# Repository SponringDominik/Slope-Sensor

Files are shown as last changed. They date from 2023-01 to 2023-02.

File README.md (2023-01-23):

# Building a slope-sensor for ski mountaineering

The danger of avalanches is directly related to the slope. Measuring slopes
during ski touring helps getting a better feeling for the terrain, and thus,
avoiding dangerous routes. In addition, it can be a helpful argumentation aid to find out whether a face really has its >50° as stated in the guidebook or a rather more realistic 42°.

Since we were too stingy to spend 85 EUR on the [slope sensor by Pieps](https://www.pieps.com/produkt/30-plus-xt), 
we rather spent 300 EUR on material and several weekends of our time to make our
own one. In this document, we lay out what we learned and provide instructions
how to build your own. 

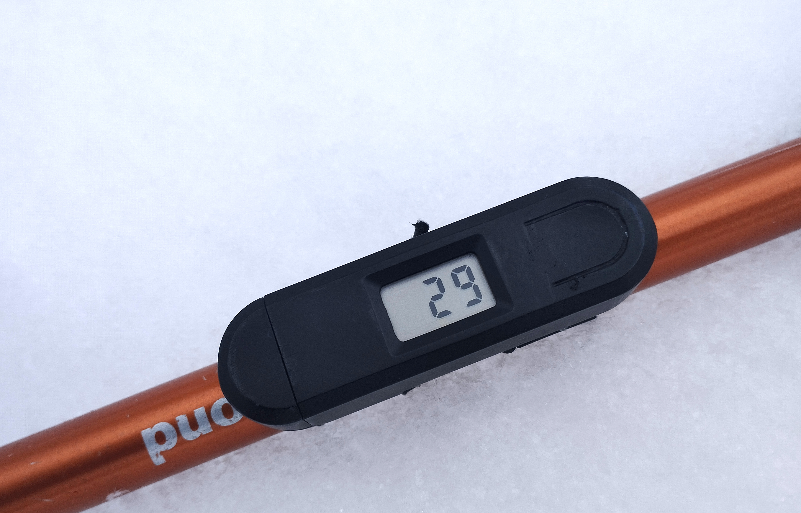
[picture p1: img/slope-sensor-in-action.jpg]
slope-sensor


## Specification of the final product:
Our product showed the following specifications, which we measured: 
  
Weight: < 20g  
Dimension(LxWxT): 75x21.5x12  
Standby current: <300nA  
Active current: <400µA  
  
The estimated battery life is >10 years in standby or >20k measurements, whichever comes first.

## Operating principle
The product is designed to be mounted on a ski pole to ensure a more robust measurement of the slope. For this purpose, it has two rubber cords with which it can be attached to the ski pole. Pressing the button on the right side awakes the device from sleep-mode and displays the slope angle. Each subsequent press toggles between the slope-measurement-mode and the temperature-measurement-mode. 20 seconds after the last press of the button, the device automatically switches to sleep-mode.

```mermaid
stateDiagram-v2
    [*] --> sleep: insert battery
    sleep --> slope: button
    slope --> temperature: button
    temperature --> slope: button
    temperature --> sleep: 20s
    slope --> sleep: 20s
```

## Choosing components
The first component to be selected was the display, because it governs the size of the device and its power consumption. We decided on a 7-segment LCD with 4 digits. The outer right digit is completely covered by the housing and electrically inaccessible. Of the outer left digit, only segment G is used to create a negative sign. To control the LCD, an LCD-driver is required that can address at least 15 segments. 

We chose a 3-axis accelerometer to measure the tilt angle. The accelerometer is aligned so that its X-axis is parallel to the pole axis. To obtain the tilt angle, the angle between the acceleration vector - which at rest corresponds to the gravity vector - and the X-component of the acceleration vector must be calculated.

<p align="center">
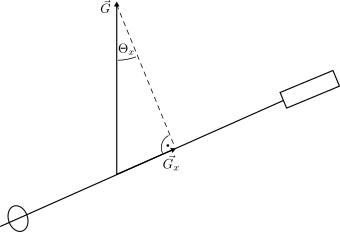
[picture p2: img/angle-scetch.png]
  
</p>

$$\Theta_x = \arcsin{\Bigg(\frac{|\vec{G}_x|}{|\vec{G}|}\Bigg)}$$

An ATtiny424 microcontroller orchestrates communication with the components and performs the calculations. 

For the power supply a 3V lithium button cell is used. The size of the battery is chosen such that it just fits into the housing of the device. A CR-1225 is most suitable and can usually supply at least 40mAh.

The following table lists all the components used on the PCB.
No | Component | Specification | Quantity | Manufacturer Product Number
-|-|-|-|-
U1 | Microcontroller | [ATtiny424](https://www.digikey.at/en/products/detail/microchip-technology/ATTINY424-SSU/13415020) | 1 | ATTINY424-SSU
U2 | Accelerometer | [MC3632](https://www.digikey.at/en/products/detail/memsic-inc/MC3632/15292805) | 1 | MC3632
U3 | Display Driver | [BU91796](https://www.digikey.at/en/products/detail/rohm-semiconductor/BU91796FS-ME2/12359485) | 1 | BU91796FS-ME2
U4 | LCD | [DE117](https://www.tme.eu/at/details/de117-rs-20_7.5/digitale-lcd-displays/display-elektronik/de-117-rs-20-7-5-v) | 1 | DE 117-RS-20/7,5
TH1 | PTC-Resistor | [TMP64](https://www.digikey.at/en/products/detail/texas-instruments/TMP6431DECR/11635694) | 1 | TMP6431DECR
SW1 | Switch | [PTS636](https://www.digikey.at/en/products/detail/c-k/PTS636-SK25F-SMTR-LFS/10071743) | 1 | PTS636 SK25F SMTR LFS
BT1 | Battery Holder | [BH-127A-1](https://www.digikey.at/en/products/detail/adam-tech/BH-127A-1/13537744) | 1 | BH-127A-1
C1 | Capacitor | [100n](https://www.digikey.at/en/products/detail/kemet/C0805C104M3RAC7800/2211748) | 1 | C0805C104M3RAC7800
R1,R2 | Resistor | [4k7](https://www.digikey.at/en/products/detail/stackpole-electronics-inc/RMCF0805FT4K70/1760659) | 2 | RMCF0805FT4K70
R3 | Resistor | [47k](https://www.digikey.at/en/products/detail/stackpole-electronics-inc/RMCF0805FT47K0/1760299) | 1 | RMCF0805FT47K0

The following table lists all the other components used to build this slope sensor. A link to an example is also listed for each component.
Part | Specification
-|-
Connector | [ZEC 1,0/ 3-ST-3,5 C1 R1,3](https://www.digikey.at/en/products/detail/phoenix-contact/1893698/2553237)
Battery | [CR1225](https://www.conrad.at/de/p/gp-batteries-gppbl1225000-knopfzelle-cr-1225-lithium-62-mah-3-v-1-st-2446350.html)
O-Ring | [10.5 x 1.5](https://www.o-ring-stocks.eu/o-ring-10.5x1.5-nbr-nitrile-70-shore-a-black-ors113871)
Screw | [ISO 7050 - ST2,2 x 6,5 - A4-20H - C - H](https://online-schrauben.de/shop/Schrauben/Blechschrauben/DIN-7982-Form-CH-Senkkopf-Blechschrauben-mit-Phillips-Kreuzschlitz-und-Spitze-aehnl.-ISO-7050/Edelstahl-Ros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,2-mm-Schraubendurchmesser)
Rubber cord | [2mm](https://www.amazon.de/perdix-Gummischnur-Gummikordel-Gummiband-Rucksack/dp/B0BB4V88YH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)

## Prototyping

## Programming the microcontroller

## CAD

## 3D-printing the case

## Final tests

## Conclusions

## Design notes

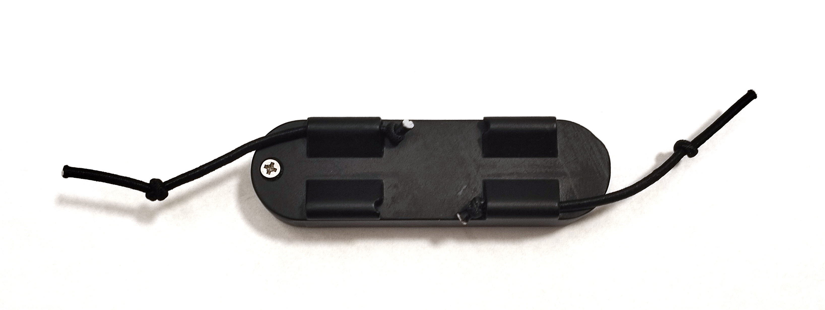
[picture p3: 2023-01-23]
img/slope-sensor-bottom.jpg

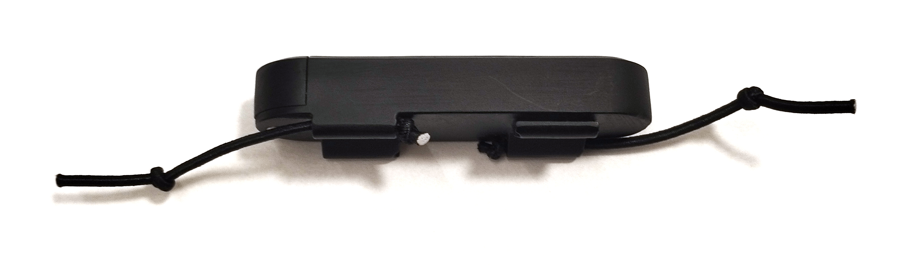
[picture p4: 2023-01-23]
img/slope-sensor-side.jpg

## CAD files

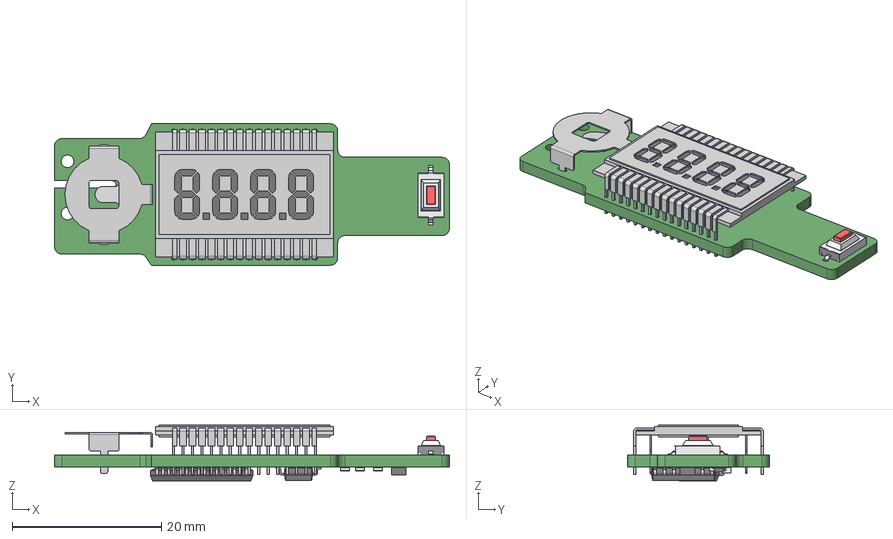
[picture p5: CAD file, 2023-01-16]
CAD/PCB.step
53.0 x 19.0 x 7.47 mm

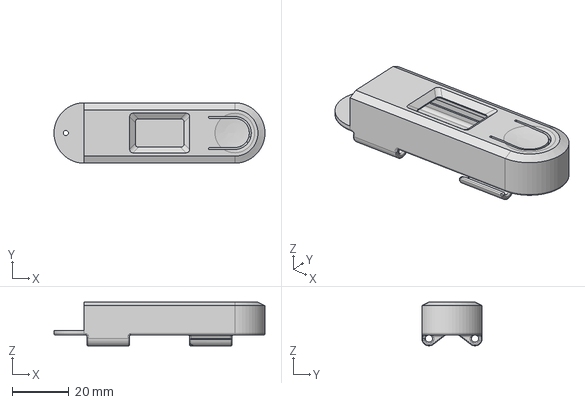
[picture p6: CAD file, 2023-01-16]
CAD/Case.step
74.7 x 21.4 x 15.5 mm

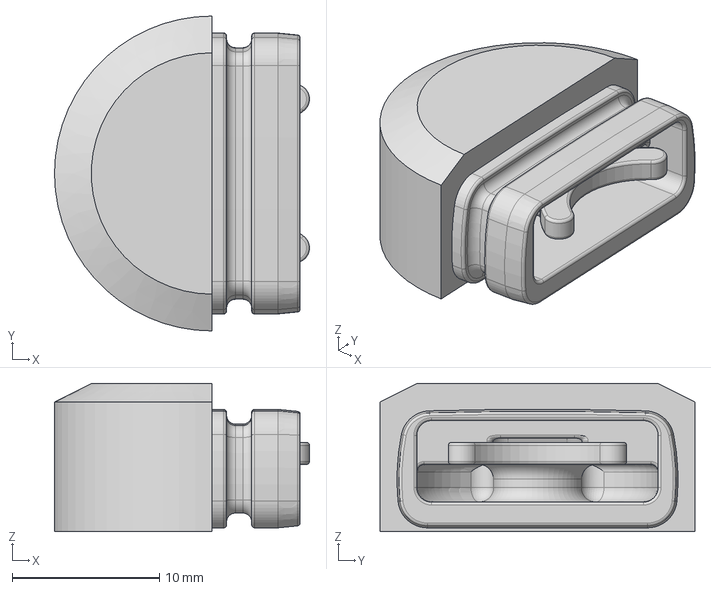
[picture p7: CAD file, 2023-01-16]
CAD/Cap.step
17.3 x 21.4 x 10.1 mm

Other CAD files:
CAD/Slope-Sensor_asm.f3z

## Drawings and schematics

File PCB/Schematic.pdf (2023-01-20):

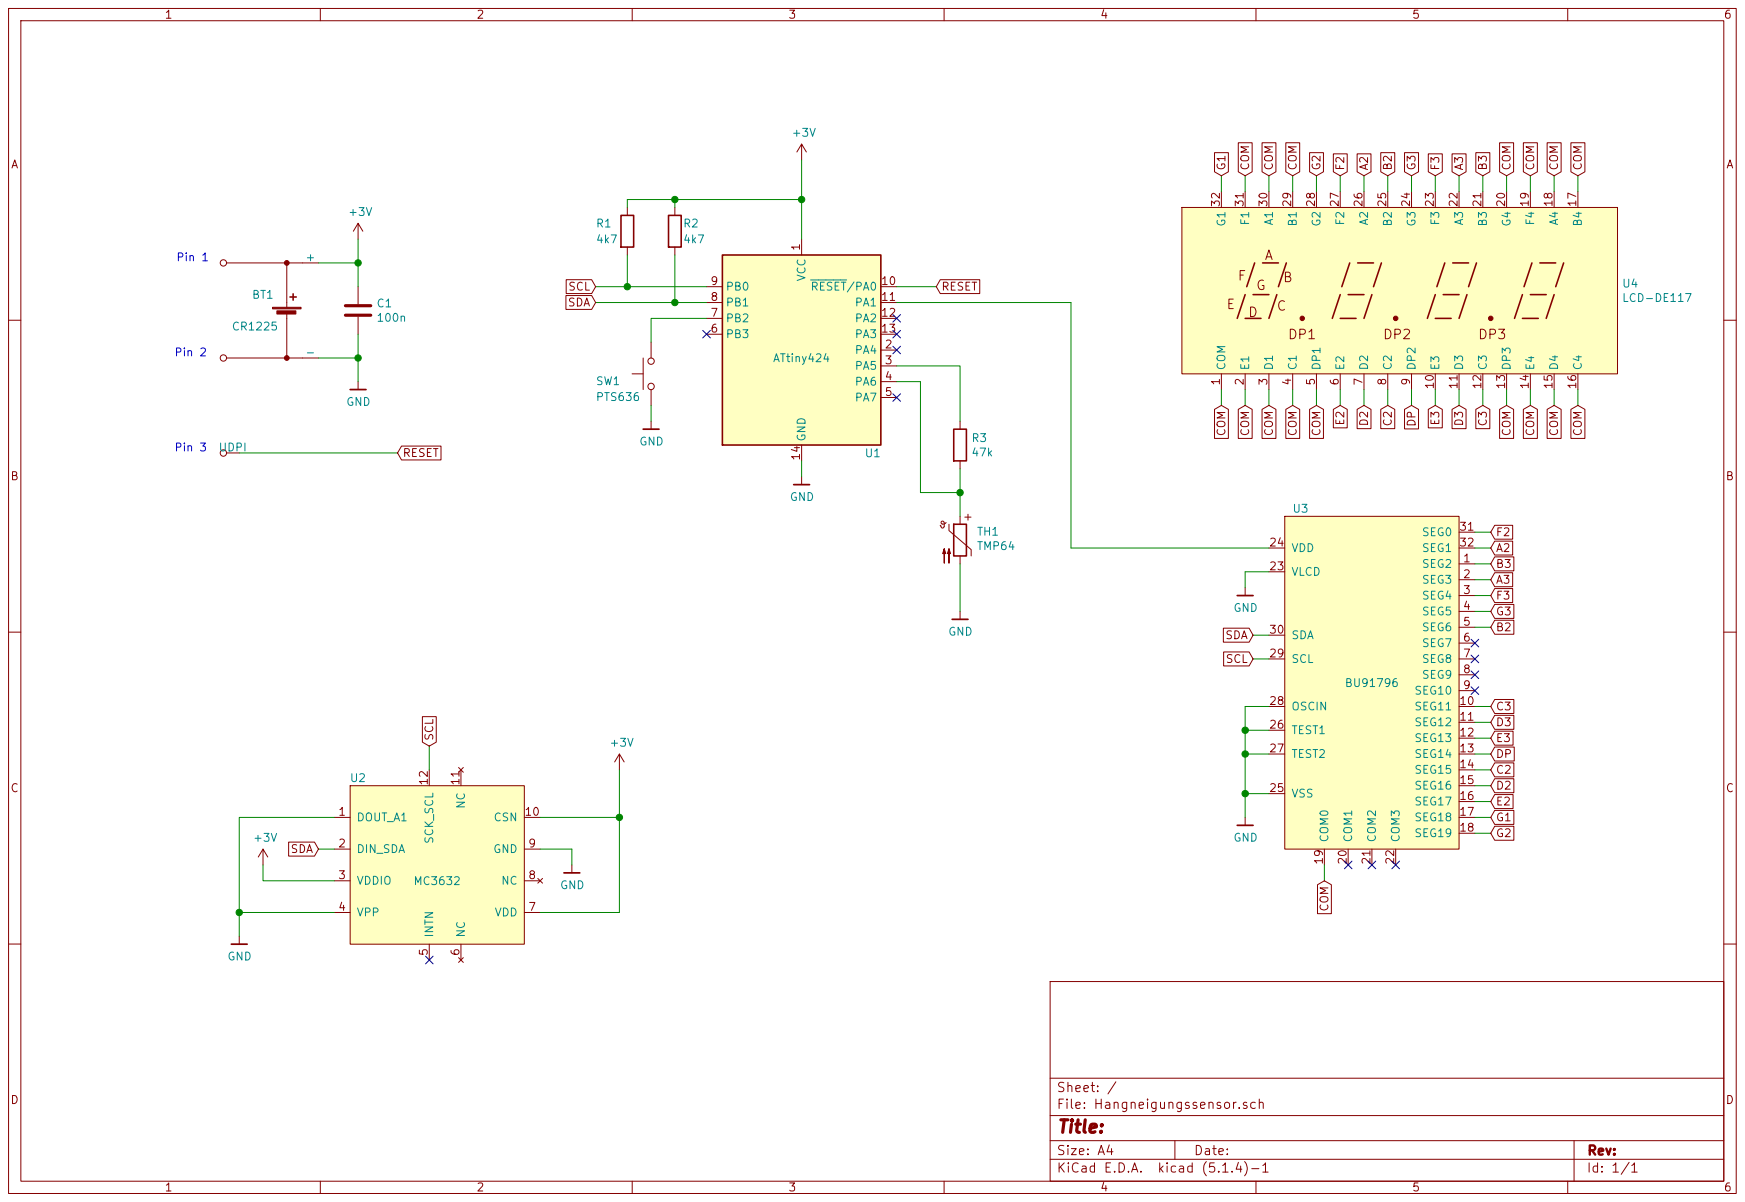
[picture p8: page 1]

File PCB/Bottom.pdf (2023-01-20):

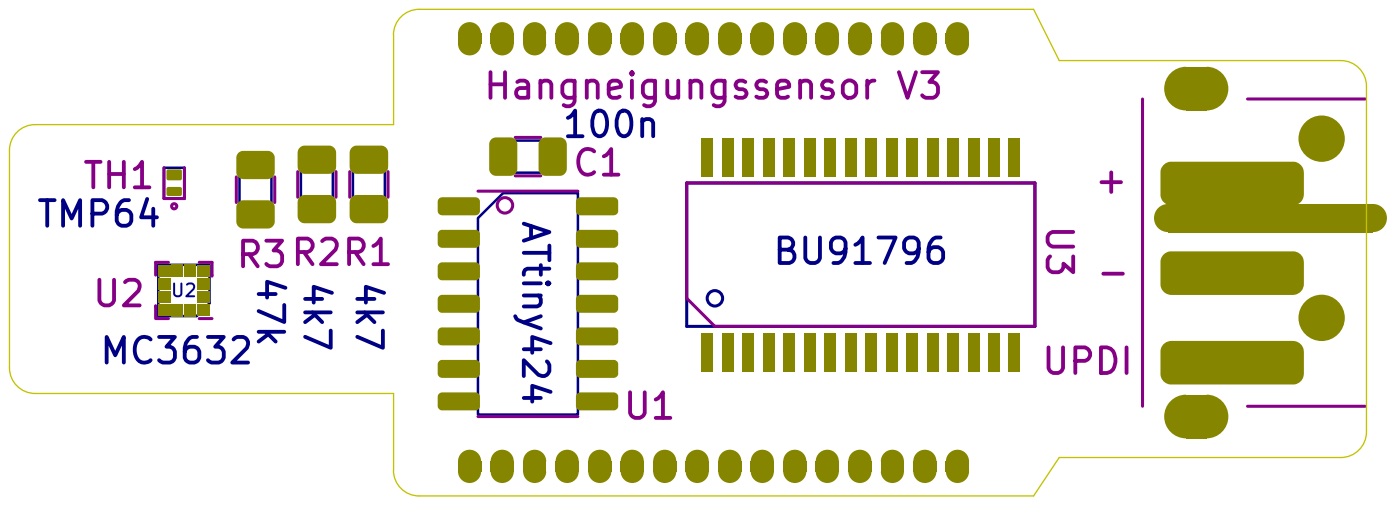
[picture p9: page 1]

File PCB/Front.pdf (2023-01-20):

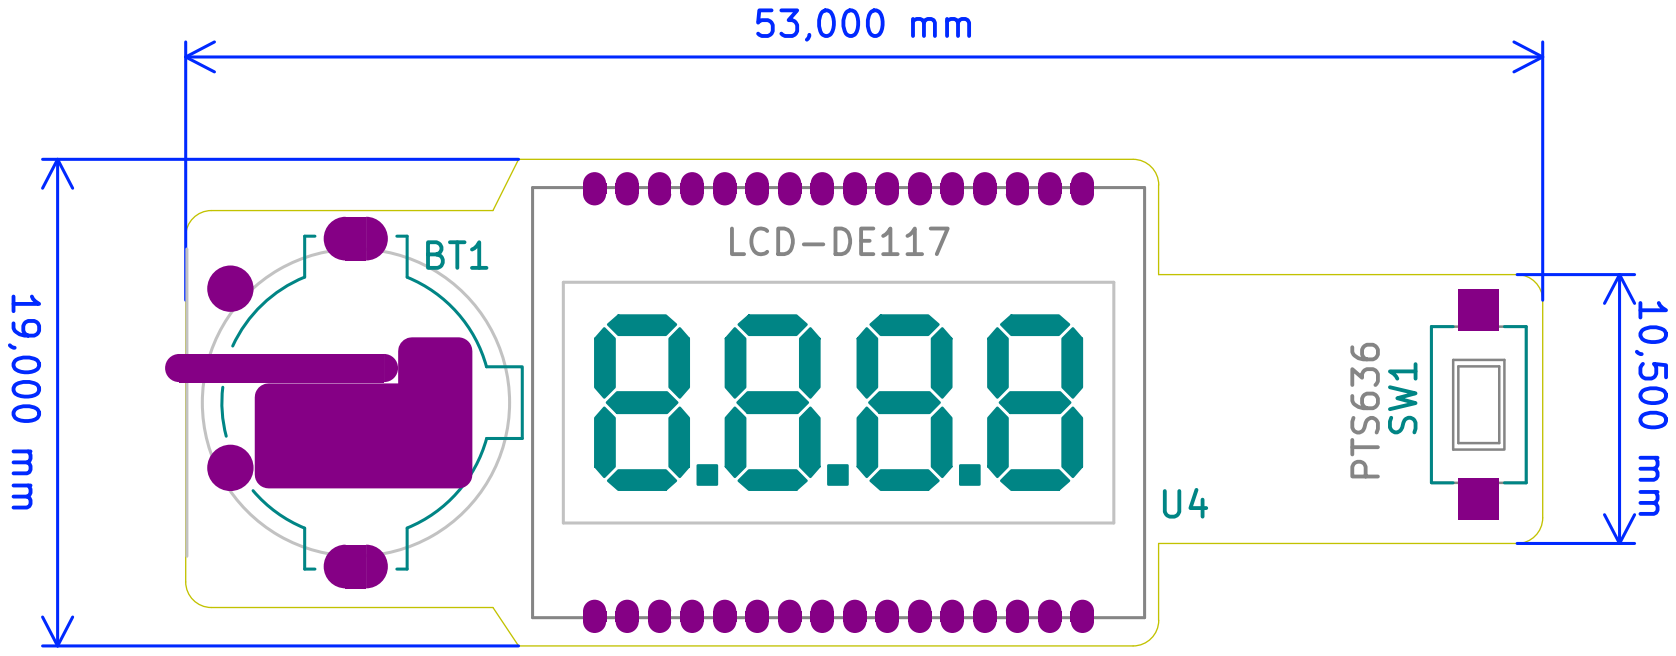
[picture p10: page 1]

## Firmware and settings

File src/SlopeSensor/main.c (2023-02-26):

/************************************************************************/
/* SlopeSensor															*/
/************************************************************************/
#include <avr/io.h>
#include <avr/interrupt.h>
#include <stdlib.h>
#include <math.h>
#include <stdbool.h>
#include "mcu_init.h"
#include "i2c_master.h"
#include "accel_util.h"
#include "lcd_util.h"

/*------------------------------------------------------------------------------------*/
// Zeit, die der Microcontrollers nach Tasterbetätigung wach bleibt in 10ms
#define WAKE_TIME 2000
// Entprell-Zeit des Tasters in 10ms
#define DEBOUNCE 10
// Vorwiderstand des Thermistors R3:
//	0: NTC-Variante
//	1: PTC-Variante
#if (0)
#  define R3_PTC 46250
#else
#  define R3_NTC 10700
#endif



/* Globale Variablen -----------------------------------------------------------------*/
// Laufzeit in 10ms
uint16_t millisecond_10;
// Laufzeit, bis der Microcontroller schlafen geht in 10ms
uint16_t sleep_at_millis = WAKE_TIME;
// Bis zu dieser Zeit wird eine Zustandsänderung des Tasters ignoriert (Prellen)
uint16_t wait_time = 0;
// Zustand des Sensors:
//		0: Winkel messen
//		1: Temperatur messen
uint8_t State = 0;


/*------------------------------------------------------------------------------------*/
/* Power-Save aktivieren */
void go_sleep(void){
	// Timer Stoppen
	TCA0.SINGLE.CTRLA &= ~TCA_SINGLE_ENABLE_bm;	
	// Accelerometer ausschalten
	accel_gosleep();
	// Display ausschalten
	PORTA.OUTCLR = LCD_EN;	// Schalte Versorgung für LCD aus
	// Zustände wieder zurücksetzen
	millisecond_10 = 0;
	State = 0;
	sleep_at_millis = WAKE_TIME;
	wait_time = 0;
	// Interrupt für Flankenänderung aktivieren
	PORTB.PIN2CTRL &= ~PORT_ISC_gm;
	PORTB.PIN2CTRL |=PORT_ISC_BOTHEDGES_gc;	
	// Schlafen gehen
	// Sleep-Mode auf Power-Down stellen und Sleep-Enable aktivieren
	SLPCTRL.CTRLA = SLPCTRL_SEN_bm | SLPCTRL_SMODE_PDOWN_gc;
	// Assembler Befehl "Sleep" startet ausgewälten Sleep-Modus
	// Sleep-Enable muss davor gesetzt werden (möglichst direkt davor)
	asm("SLEEP");
	
	
	// Wake-Up Sequenz
	// Accelerometer aktivieren
	accel_wakeup();
	// Versorgung für LCD einschalten
	PORTA.OUTSET = LCD_EN;
	lcd_init();
	// Timer zurücksetzen und starten
	TCA0.SINGLE.CNTL = 0;
	TCA0.SINGLE.CNTH = 0;
	TCA0.SINGLE.CTRLA |= TCA_SINGLE_ENABLE_bm;
}

/* Ruhemodus aktivieren */
void go_idle(void){
	// Sleep-Mode auf IDLE stellen und Sleep-Enable aktivieren
	SLPCTRL.CTRLA = SLPCTRL_SEN_bm | SLPCTRL_SMODE_IDLE_gc;
	// Assembler Befehl "Sleep" startet ausgewälten Sleep-Modus
	// Sleep-Enable muss davor gesetzt werden (möglichst direkt davor)
	asm("SLEEP");
}


#ifdef R3_NTC
/* Lese ADC aus und berechne Temperatur */
int8_t get_temperature(void){
	// Tabelle des NTC:
	// Enthält Widerstandswerte zu bekannten Temperaturen von -40°C bis 40°C in 5°C Schritten
	uint32_t R_NTC_Table[17] = {205200, 154800, 117900, 90690, 70370, 55070, 43440, 34530, 
								27640, 22270, 18060, 14740, 12110, 10000, 8309, 6941, 5828};
	// Starte AD Konvertierung
	ADC0.COMMAND = ADC0.COMMAND | ADC_START_IMMEDIATE_gc;
	// Warte auf Ergebniss
	while(!(ADC0.INTFLAGS & ADC_RESRDY_bm));
	// Lese ADC aus
	uint32_t raw_ADC = ADC0.RESULT;
	// Berechne Widerstandswert
	uint32_t R_NTC = raw_ADC*R3_NTC/(4096 - raw_ADC);
	
	// Berechne Temperatur mithilfe linearer Interpolation aus der TEMP-Tabelle
	uint32_t X1, X2;	// Unterer und oberer Widerstandswert
	// Falls Widerstand größer als größter Wert in Tabelle:
	X1 = R_NTC_Table[0];
	if(R_NTC > X1) return -88;
	// Suche ersten Wert, der größer als der gemessene Wert ist
	for(uint8_t i=1; i<17; i++){
		X2 = R_NTC_Table[i];
		if(R_NTC > X2){
			X1 = R_NTC_Table[i-1];
			// Interpoliere zwischen Werten
			return lrint(-45 + i*5 + ((float)(X1 - R_NTC) / (X1 - X2)) * 5);
		}
	}
	// Falls Widerstand kleiner als kleinster Wert in Tabelle:
	return 88;
}
#endif
#ifdef R3_PTC
/* Lese ADC aus und berechne Temperatur */
int8_t get_temperature(void){
	// Tabelle des PTC:
	// Enthält Widerstandswerte zu bekannten Temperaturen von -40°C bis 40°C in 5°C Schritten
	uint16_t R_PTC_Table[17] = {30230, 31234, 32268, 33332, 34427, 35554, 36713, 37905, 39129,
								40387, 41679, 43006, 44367, 45763, 47194, 48661, 50164};
	// Starte AD Konvertierung
	ADC0.COMMAND = ADC0.COMMAND | ADC_START_IMMEDIATE_gc;
	// Warte auf Ergebniss
	while(!(ADC0.INTFLAGS & ADC_RESRDY_bm));
	// Lese ADC aus
	uint16_t raw_ADC = ADC0.RESULT;
	// Berechne Widerstandswert
	uint16_t R_PTC = raw_ADC*R3_PTC/(4096 - raw_ADC);
	
	// Berechne Temperatur mithilfe linearer Interpolation aus der TEMP-Tabelle
	uint16_t X1, X2;	// Unterer und oberer Widerstandswert
	// Falls Widerstand kleiner als kleinster Wert in Tabelle:
	X1 = R_PTC_Table[0];
	if(R_PTC < X1) return -88;
	// Suche ersten Wert, der größer als der gemessene Wert ist 
	for(uint8_t i=1; i<17; i++){
		X2 = R_PTC_Table[i];
		if(R_PTC < X2){
			X1 = R_PTC_Table[i-1];
			// Interpoliere zwischen Werten
			return lrint(-45 + i*5 + ((float)(R_PTC - X1) / (X2 - X1)) * 5);
		}
	}
	// Falls Widerstand größer als größter Wert in Tabelle:
	return 88;
}
#endif


/* Berechne den Neigungswinkel */
uint8_t calc_theta(int32_t X, int32_t Y, int32_t Z){
	int8_t theta = lrint(asin(X/sqrt(X*X + Y*Y + Z*Z))*180/M_PI);
	return abs(theta);
}




/* Main Program ----------------------------------------------------------------------*/
int main(void){
	MCU_init();			// Initierung des Microcontrollers
	i2c_init();			// Initierung des I2C-Bus
	accel_init();		// Initierung des Beschleunigungssensors

	// Interrupts aktivieren
	sei();
	// Nach Initialisierung -> Sleep
	go_sleep();
	
	
/* Main Loop --------------------------------------------------------------------------*/
	while (1){
		// Wenn Zeit abgelaufen -> Sleep
		if(millisecond_10 > sleep_at_millis) go_sleep();
		
		// Verhindert zu langes Warten beim Umschalten von 
		// Winkelmessung zu langsamer Temp-Messung
		static bool instantRun = false;
		// Alter Tasterzustand
		static bool button_old = true;
		// Neuer Tasterzustand (Taster schaltet auf Gnd)
		bool button = !(PORTB.IN & BUTTON);
		// Positive Flanke & außerhalb der Prell-Zeit:
		if(button && !button_old && (millisecond_10 > wait_time)){
			// Wartezeit zum entprellen setzen
			wait_time = millisecond_10 + DEBOUNCE;
			// Wachzeit verlängern
			sleep_at_millis = millisecond_10 + WAKE_TIME;
			// Zustand umschalten
			if(State == 0){
				State = 1;
				instantRun = true;
			}else{
				if(State == 1) State = 0;
			}
		}
		button_old = button;
		
		// Winkel messen
		if(State == 0){
			// Alle 0.2s wird Wert aktualisiert
			if(millisecond_10%20 == 1){
				// Lese Beschleunigungswerte
				uint8_t* v_accel = read_acceleration();
				// Erstelle aus den 6 Byte 3 Beschleunigungswerte
				int16_t X, Y, Z;
				X = v_accel[0] | (v_accel[1] << 8);
				Y = v_accel[2] | (v_accel[3] << 8);
				Z = v_accel[4] | (v_accel[5] << 8);
				// Berechne Neigungswinkel der Längsachse
				uint8_t theta_Y = calc_theta(Y, X, Z);
				// Neigungswinkel anzeigen
				lcd_write(theta_Y);
			}
		}
		// Temperatur messen
		if(State == 1){
			// Alle 1s wird Wert aktualisiert oder direkt nach umschalten des Zustands
			if(millisecond_10%100 == 1 || instantRun){
				instantRun = false;
				// Stromversorgung aktivieren
				PORTA.OUTSET = TEMP_EN;
				// Temperaturwert messen
				int8_t temperature = get_temperature();
				// Stromversorgung deaktivieren
				PORTA.OUTCLR = TEMP_EN;
				// Temperaturwert anzeigen
				lcd_write(temperature);
			}
		}
		// Ruhemodus aktivieren

		go_idle();
	}
}


/* Interrupts -------------------------------------------------------------------------*/

/* Interrupt für Flankenänderung an PINB2 -> Taster gedrückt */
ISR(PORTB_PORT_vect){
	uint8_t intflags = PORTB.INTFLAGS;
	PORTB.INTFLAGS = intflags;
	// Interrupt deaktivieren
	PORTB.PIN2CTRL &= ~PORT_ISC_gm;
	// Sleep disable
	SLPCTRL.CTRLA = 0;
}
/* Interrupt für Timer-Overflow -> 1ms vergangen */
ISR(TCA0_OVF_vect){
	uint8_t intflags = TCA0.SINGLE.INTFLAGS;
	TCA0.SINGLE.INTFLAGS = intflags;
	// Zeit um 1ms erhöhen
	millisecond_10 += 1;
}

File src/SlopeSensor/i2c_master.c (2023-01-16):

/************************************************************************/
/* I2C-Master-Library für ATTINY der Serie2                             */
/************************************************************************/
#include <avr/io.h>
#include <math.h>
#include <util/delay.h>

// Definiere CPU Frequenz in Hz, falls nicht schon definiert
#ifndef F_CPU
#define F_CPU 1000000UL
#endif
// I2C Frequenz in Hz
#define F_SCL  50000L




/* Sende ACK-Zeichen gefolgt von Stop-Zeichen */
void i2c_stop(void){
	TWI0.MCTRLB = TWI_ACKACT_ACK_gc | TWI_MCMD_STOP_gc;
}


/* Sende NACK-Zeichen gefolgt von Stop-Zeichen */
void i2c_stop_NACK(void){
	TWI0.MCTRLB = TWI_ACKACT_NACK_gc | TWI_MCMD_STOP_gc;
}


/* Sende ACK-Zeichen gefolgt von Start-Zeichen */
void i2c_restart(void){
	TWI0.MCTRLB = TWI_ACKACT_ACK_gc | TWI_MCMD_REPSTART_gc;
}


/* Sende ACK-Zeichen */
void i2c_ACK(void){
	TWI0.MCTRLB = TWI_ACKACT_ACK_gc | TWI_MCMD_RECVTRANS_gc;
}


/* Sende NACK-Zeichen */
void i2c_NACK(void){
	TWI0.MCTRLB = TWI_ACKACT_NACK_gc | TWI_MCMD_RECVTRANS_gc;
}


/* Initialisierung des I2C (Master-Mode) */
void i2c_init(void){
	// Mit MBAUD kann die Bus-Frequenz eingestellt werden.
	// BAUD muss innerhalb gewisser Grenzen liegen (siehe Datenblatt)
	// t_R = 1µs
	// t_OF = 250ns
	// t_LOW_min = 4.7µs
	#define BAUD ((uint8_t) ceil(F_CPU/(2*F_SCL) - (5 + F_CPU*1E-6/2)))
	//#define BAUD ((uint8_t) ceil(F_CPU*(4.7E-6 + 250E-9) - 5))
	TWI0.MBAUD = BAUD;
	TWI0.MCTRLA = TWI_ENABLE_bm;				// Master aktivieren
	TWI0.MSTATUS = TWI_BUSSTATE_IDLE_gc;		// Bus-state auf Idle stellen
}


/* Kontrolliere den Status des I2C */
uint8_t i2c_check(void){
	uint8_t state;
	// Warte auf Antwort der beiden Interrupt-Flags
	while(!(TWI0.MSTATUS & (TWI_WIF_bm | TWI_RIF_bm))){
		// Lese Status-Register und überprüfe, ob Fehler erkannt wurde
		state = TWI0.MSTATUS;
		if(state & TWI_BUSERR_bm) return 1;
		if(state & TWI_ARBLOST_bm) return 1;
	}
	// Lese Status-Register
	state = TWI0.MSTATUS;
	// Wenn NACK empfangen -> Stop-Zeichen senden und abbrechen
	if(state & TWI_RXACK_bm){
		i2c_stop();
		return 1;
	}
	// Ist I2C-Master BUS-Owner?
	if((state & TWI_BUSSTATE_gm) == TWI_BUSSTATE_OWNER_gc){
		return 0;
	}
	else{
		return 1;
	}
}


/* Starte Busverbindung mit 8-Bit Adresse (R/W includiert) */
uint8_t i2c_start(uint8_t address){
	// Falls Bus-State Busy ist, Neustart des Bus und 5ms warten
	if((TWI0.MSTATUS & TWI_BUSSTATE_gm) == TWI_BUSSTATE_BUSY_gc){
		TWI0.MCTRLB |= TWI_FLUSH_bm;
		_delay_ms(5);
	}
	// Adresse senden und Bus-State überprüfen
	TWI0.MADDR = address;
	return i2c_check();
}


/* Starte Busverbindung in Lese-Modus */
uint8_t i2c_start_read(uint8_t address){
	return i2c_start((address << 1) + 1);
}


/* Starte Busverbindung in Schreibe-Modus */
uint8_t i2c_start_write(uint8_t address){
	return i2c_start(address << 1);
}


/* Sende Daten */
uint8_t i2c_write(uint8_t data){
	// Daten senden und Bus-State überprüfen
	TWI0.MDATA = data;
	return i2c_check();
}


/* Lese Daten */
uint8_t i2c_read(void){
	// Warte auf Daten
	while(!(TWI0.MSTATUS & TWI_RIF_bm)){
		// Lese Status-Register und überprüfe, ob Fehler erkannt wurde
		uint8_t state = TWI0.MSTATUS;
		if(state & TWI_BUSERR_bm) return 1;
		if(state & TWI_ARBLOST_bm) return 1;
	}
	return TWI0.MDATA;
}

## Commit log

2023-01-16 Add CAD-files
    [Cap.step, Case.step, PCB.step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]
2023-01-16 Add PCB files
    [Hangneigungssensor.kicad_pcb, Hangneigungssensor.sch]
2023-01-20 Improved annotation
    [Hangneigungssensor.kicad_pcb, Hangneigungssensor.sch]
2023-02-26 exchanged entire project
    Since there were problems with opening the project, everything was re-inserted.
    [accel_util.c, i2c_master.c, lcd_util.c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]
